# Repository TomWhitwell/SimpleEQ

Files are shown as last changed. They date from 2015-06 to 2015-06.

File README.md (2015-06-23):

# SimpleEQ  
Learn SMD soldering by building two channels of the kind of tone controls you’d find on an old hifi. 

Top channel = Baxandall EQ, treble/bass cut/boost   
Bottom channel = Tilt EQ  

No voltage control, but just enough range to push sounds into distortion. 

Works well in a feedback loop.

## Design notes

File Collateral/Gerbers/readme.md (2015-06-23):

##Gerbers Changelog

Board Rev1.1 
- Updated Thonkiconn socket outlines

Board Rev1
- First prototype, works perfectly 

Panel Rev1
- Prototype as built, works, please check aesthetics of type/logo

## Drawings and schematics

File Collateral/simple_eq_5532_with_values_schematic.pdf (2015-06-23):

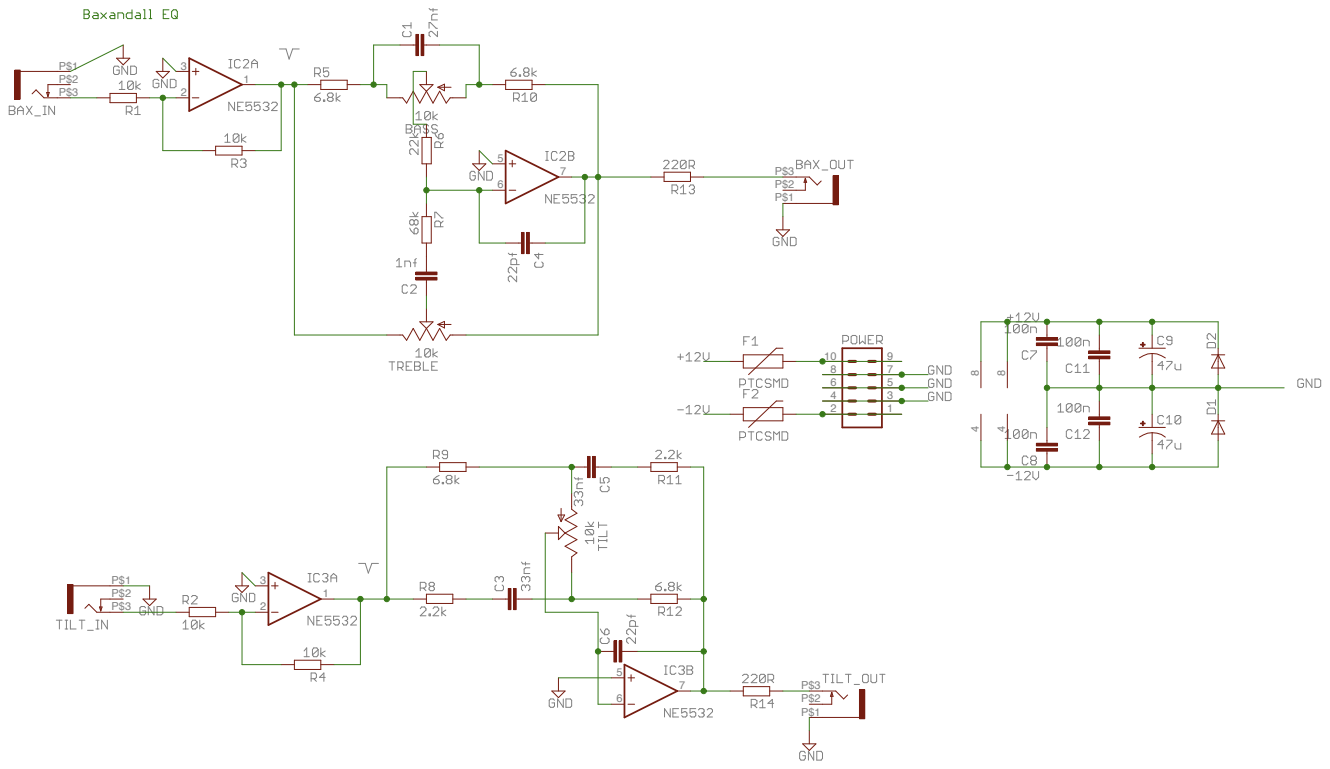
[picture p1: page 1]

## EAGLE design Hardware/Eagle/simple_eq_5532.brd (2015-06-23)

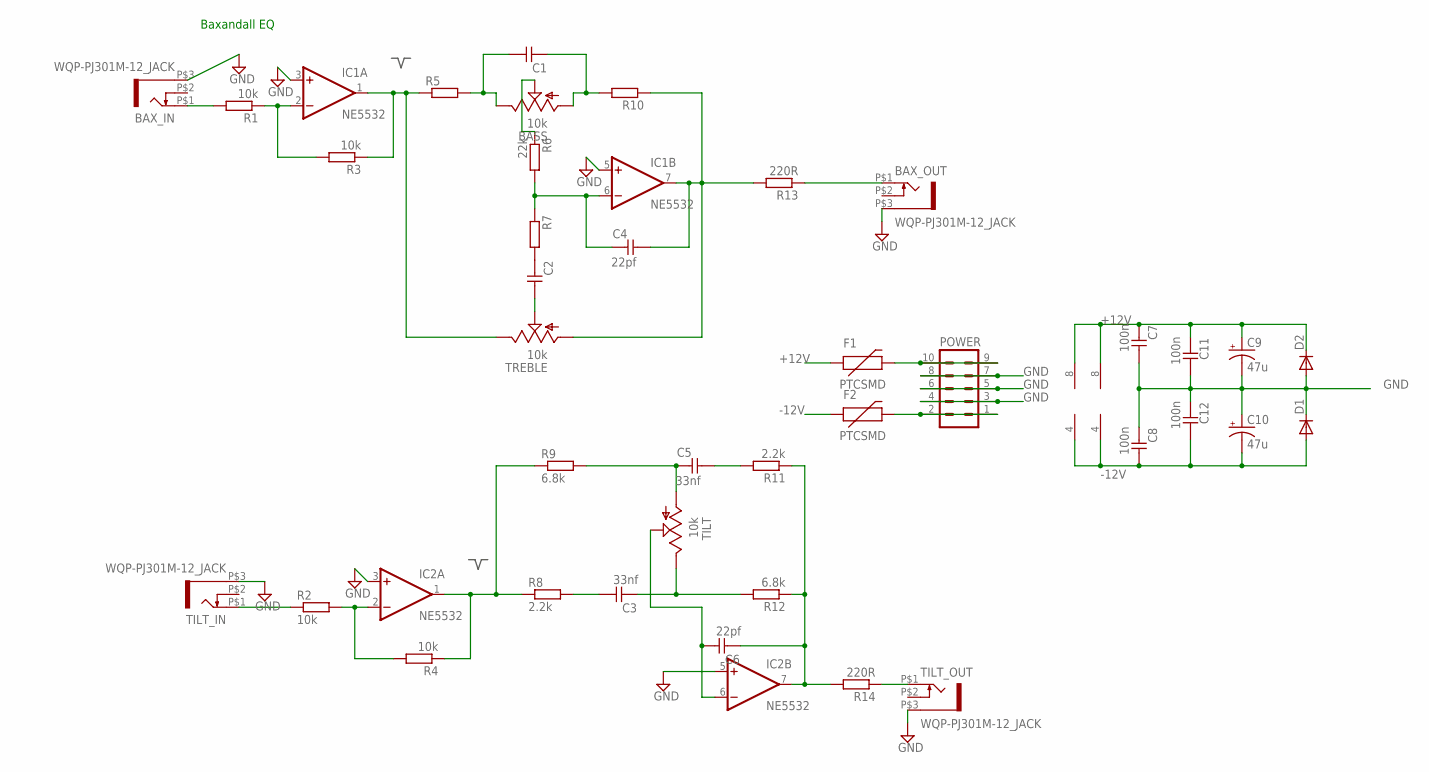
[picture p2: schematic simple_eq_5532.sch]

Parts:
BASS: 10k; EVUF
BAX_IN: WQP-PJ301M-12_JACK
BAX_OUT: WQP-PJ301M-12_JACK
C1, C2: C-EU0805_CAP; R0805
C3, C5: 33nf; R0805
C4, C6: 22pf; R0805
C7, C8, C11, C12: 100n; R0805
C9, C10: 47u; PANASONIC_D
D1, D2: DIODE-SOD123; SOD123
F1, F2: PTCSMD; PTC-1206
IC1, IC2: NE5532; SO08
POWER: 10_PIN_HEADER; MA05-2
R1, R2, R3, R4: 10k; R0805
R5, R7, R10: R-EU_R0805; R0805
R6: 22k; R0805
R8, R11: 2.2k; R0805
R9, R12: 6.8k; R0805
R13, R14: 220R; R0805
TILT: 10k; EVUF
TILT_IN: WQP-PJ301M-12_JACK
TILT_OUT: WQP-PJ301M-12_JACK
TREBLE: 10k; EVUF

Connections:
+12V: C7.2, C9.+, C11.2, D2.C, F1.1, IC1.8 (V+), IC2.8 (V+)
-12V: C8.1, C10.-, C12.1, D1.A, F2.1, IC1.4 (V-), IC2.4 (V-)
BAX1: C4.1, IC1.7 (OUT), R10.1, R13.2, TREBLE.1 (A)
BAX$1: BAX_IN.P$1 (2), R1.2
BAX$2: BAX_OUT.P$1 (2), R13.1
BAX$24: IC1.2 (-IN), R1.1, R3.2
BAX$26: C2.1, TREBLE.2 (S)
BAX$27: BASS.3 (E), C1.1, R5.2
BAX$28: BASS.1 (A), C1.2, R10.2
BAX$29: BASS.2 (S), R6.1
BAX$31: IC1.1 (OUT), R3.1, R5.1, TREBLE.3 (E)
BAX$32: C4.2, IC1.6 (-IN), R6.2, R7.1
GND: BAX_IN.P$3 (1), BAX_OUT.P$3 (1), C7.1, C8.2, C9.-, C10.+, C11.1, C12.2, D1.C, D2.A, IC1.3 (+IN), IC1.5 (+IN), IC2.3 (+IN), IC2.5 (+IN), POWER.3, POWER.4, POWER.5, POWER.6, POWER.7, POWER.8, TILT_IN.P$3 (1), TILT_OUT.P$3 (1)
unnamed: IC2.2 (-IN), R2.2, R4.2
unnamed: IC2.1 (OUT), R4.1, R8.1, R9.1
unnamed: R14.1, TILT_OUT.P$1 (2)
unnamed: R2.1, TILT_IN.P$1 (2)
unnamed: F1.2, POWER.9, POWER.10
unnamed: F2.2, POWER.1, POWER.2
unnamed: C3.1, R8.2
unnamed: C3.2, R12.2, TILT.3 (E)
unnamed: C5.2, R9.2, TILT.1 (A)
unnamed: C5.1, R11.2
unnamed: C6.1, IC2.6 (-IN), TILT.2 (S)
unnamed: C2.2, R7.2
TILT_OUT: C6.2, IC2.7 (OUT), R11.1, R12.1, R14.2

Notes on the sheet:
Baxandall EQ

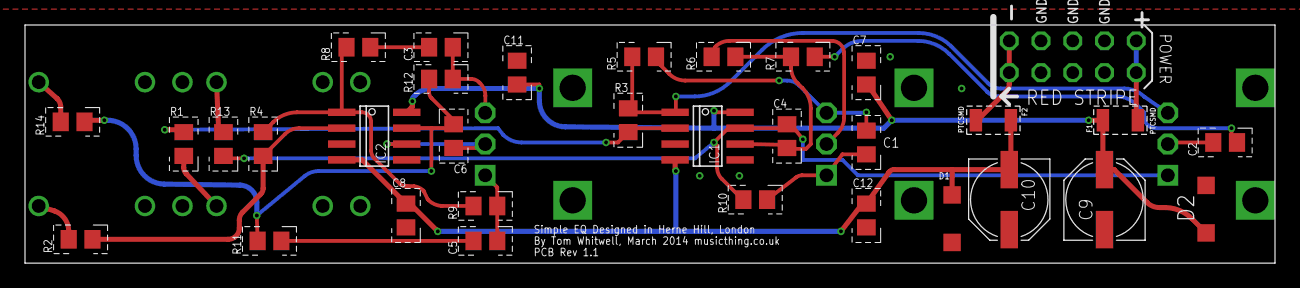
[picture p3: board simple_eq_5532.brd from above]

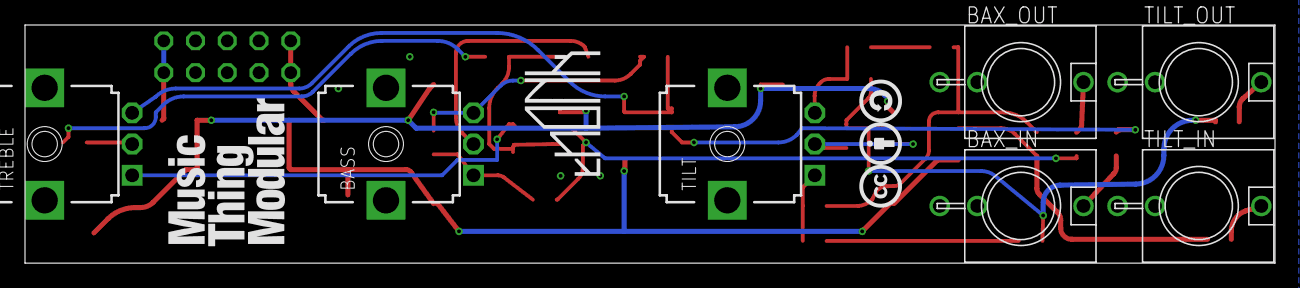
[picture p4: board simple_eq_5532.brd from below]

Board: 4 copper layers, 100.0 x 19.1 mm, 43 parts (10 on the bottom side), 26 nets.

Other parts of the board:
U$5: MTM_1CM
U$6: CC_1CM_SCREENPRINT
U$7: THONK_1CM_SCREENPRINT

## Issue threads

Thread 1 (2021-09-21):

Diodes

hanebuechenes, 2021-09-21:
Can you tell me, what kind of diodes you used?

TomWhitwell, 2021-09-21:
I normally used a 1N5819HW for the reverse polarity protection diodes - they seem to be out of stock everywhere. The board will work without them, but won't be reverse polarity protected.

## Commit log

2015-06-23 Initial bundle as first successful build
    [SMD_SimpleEQ_Panel.GBL, SMD_SimpleEQ_Panel.GBO, SMD_SimpleEQ_Panel.GBP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]
2015-06-23 Rev 1.1 updated Thonkiconn socket outlines
    [SMD_SimpleEQ_Panel.GBL, SMD_SimpleEQ_Panel.GBO, SMD_SimpleEQ_Panel.GBP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]

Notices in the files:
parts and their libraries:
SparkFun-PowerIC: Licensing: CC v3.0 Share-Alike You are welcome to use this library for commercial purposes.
